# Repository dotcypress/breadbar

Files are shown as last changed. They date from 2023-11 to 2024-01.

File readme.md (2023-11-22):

# BreadBar

Minimal STM32G0 prototyping board.

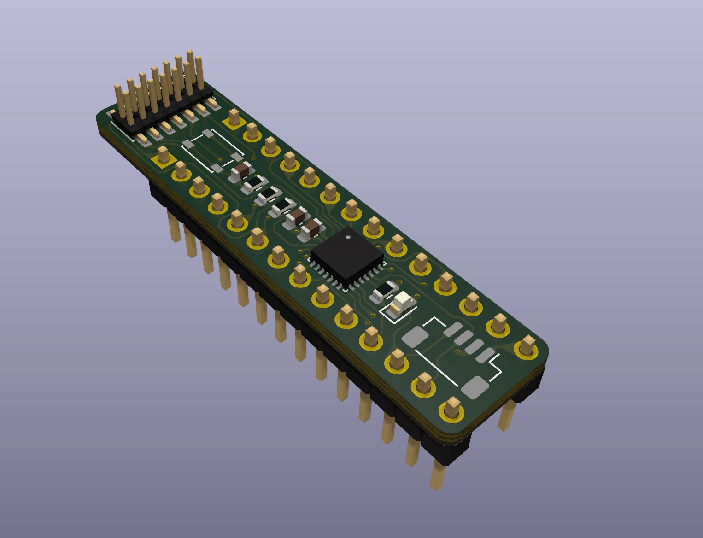
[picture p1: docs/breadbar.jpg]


## PCB

* [Schematics](docs/breadbar.pdf)
* [Gerber files](docs/breadbar_rev_0x01.zip)
* [Order PCB on OSHPark](https://oshpark.com/shared_projects/HnaNiZUA)

## Pinout

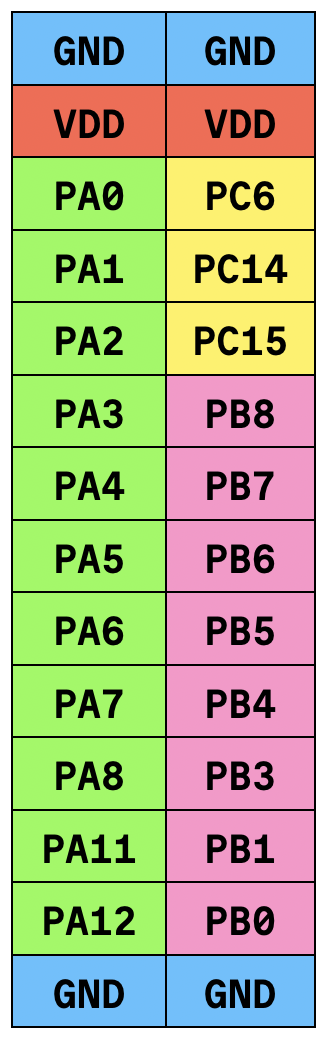
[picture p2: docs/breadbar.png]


## License

Licensed under either of

- Apache License, Version 2.0 ([LICENSE-APACHE](LICENSE-APACHE) or
  http://www.apache.org/licenses/LICENSE-2.0)
- MIT license ([LICENSE-MIT](LICENSE-MIT) or http://opensource.org/licenses/MIT)

at your option.

### Contribution

Unless you explicitly state otherwise, any contribution intentionally submitted
for inclusion in the work by you, as defined in the Apache-2.0 license, shall be
dual licensed as above, without any additional terms or conditions.

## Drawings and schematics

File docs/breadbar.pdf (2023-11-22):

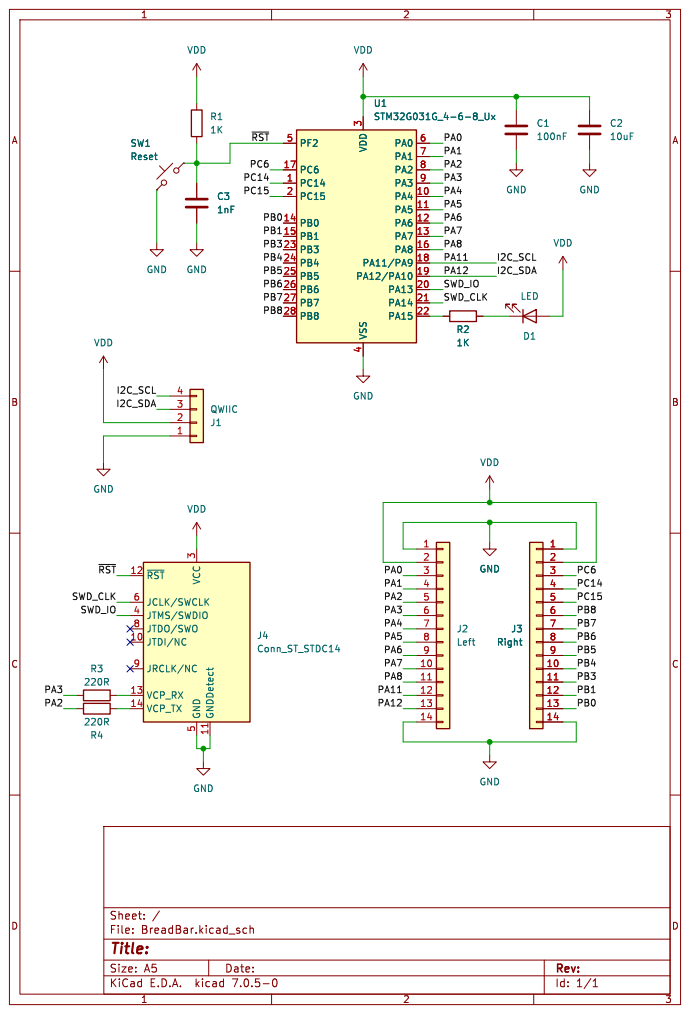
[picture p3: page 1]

VDD | VDD

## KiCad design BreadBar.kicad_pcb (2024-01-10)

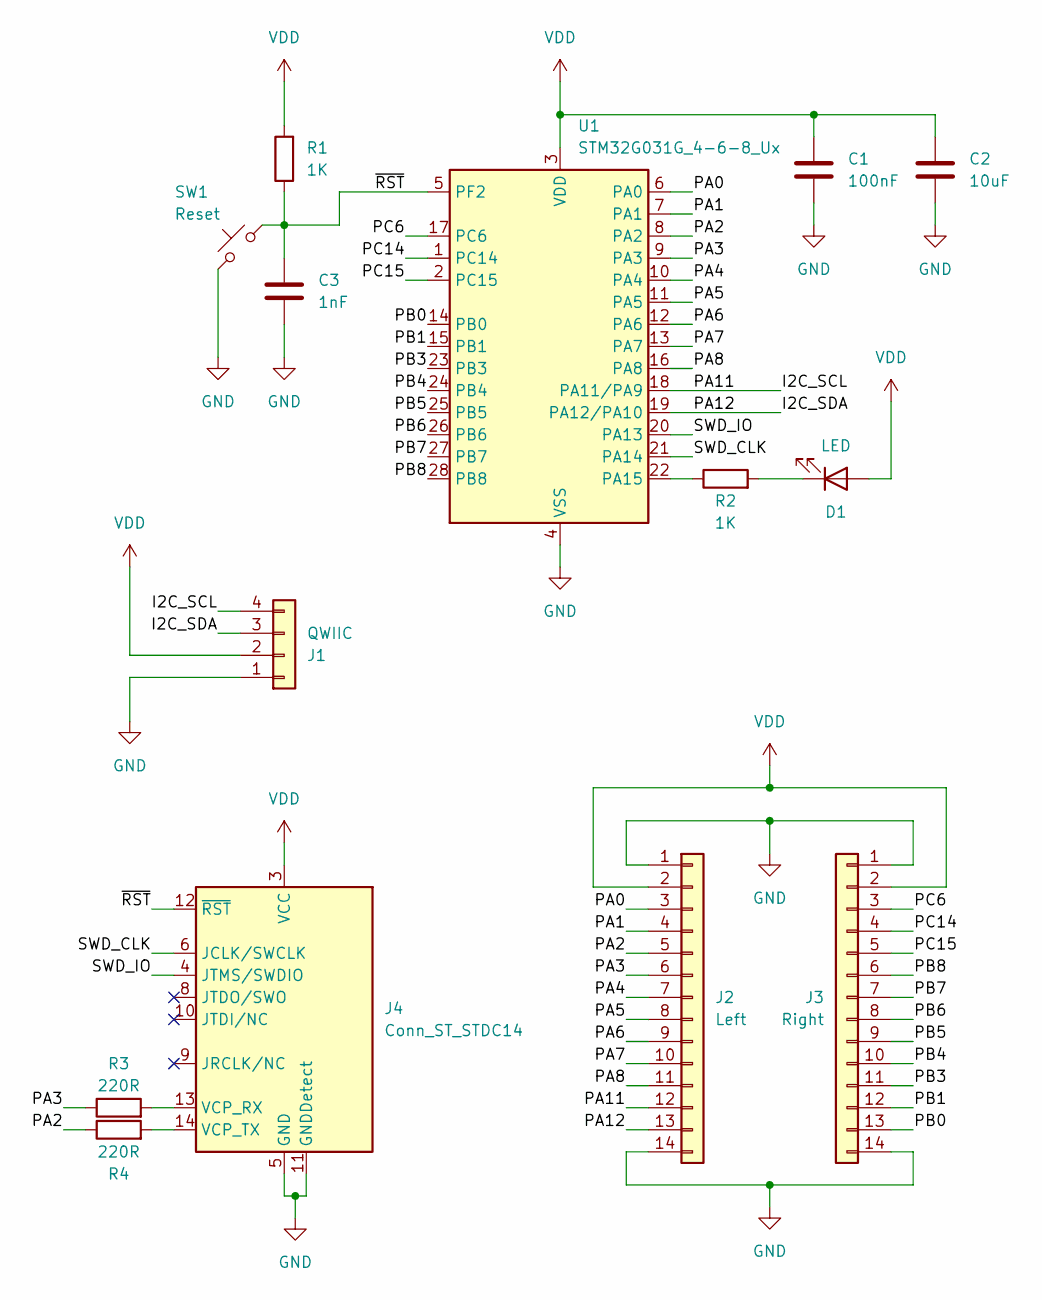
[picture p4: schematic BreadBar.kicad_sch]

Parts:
C1: 100nF; C_0603_1608Metric
C2: 10uF; C_0603_1608Metric
C3: 1nF; C_0603_1608Metric
D1: LED; LED_0603_1608Metric
J1: QWIIC; JST_SH_BM04B-SRSS-TB_1x04-1MP_P1.00mm_Vertical
J2: Left; PinHeader_1x14_P2.54mm_Vertical
J3: Right; PinHeader_1x14_P2.54mm_Vertical
J4: Conn_ST_STDC14; PinHeader_2x07_P1.27mm_Vertical_SMD
R1, R2: 1K; R_0603_1608Metric
R3, R4: 220R; R_0603_1608Metric
SW1: Reset; SW_SPST_PTS810
U1: STM32G031G_4-6-8_Ux; QFN-28_4x4mm_P0.5mm

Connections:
/I2C_SCL: J1.4, J2.12, U1.18 (PA11/PA9)
/I2C_SDA: J1.3, J2.13, U1.19 (PA12/PA10)
/PA0: J2.3, U1.6 (PA0)
/PA1: J2.4, U1.7 (PA1)
/PA2: J2.5, R4.1, U1.8 (PA2)
/PA3: J2.6, R3.1, U1.9 (PA3)
/PA4: J2.7, U1.10 (PA4)
/PA5: J2.8, U1.11 (PA5)
/PA6: J2.9, U1.12 (PA6)
/PA7: J2.10, U1.13 (PA7)
/PA8: J2.11, U1.16 (PA8)
/PB0: J3.13, U1.14 (PB0)
/PB1: J3.12, U1.15 (PB1)
/PB3: J3.11, U1.23 (PB3)
/PB4: J3.10, U1.24 (PB4)
/PB5: J3.9, U1.25 (PB5)
/PB6: J3.8, U1.26 (PB6)
/PB7: J3.7, U1.27 (PB7)
/PB8: J3.6, U1.28 (PB8)
/PC6: J3.3, U1.17 (PC6)
/PC14: J3.4, U1.1 (PC14)
/PC15: J3.5, U1.2 (PC15)
/SWD_CLK: J4.6 (JCLK/SWCLK), U1.21 (PA14)
/SWD_IO: J4.4 (JTMS/SWDIO), U1.20 (PA13)
/~RST: C3.1, J4.12 (~RST), R1.1, SW1.2, U1.5 (PF2)
GND: C1.2, C2.2, C3.2, J1.1, J2.1, J2.14, J3.1, J3.14, J4.5 (GND), J4.7 (GND), J4.11 (GNDDetect), SW1.1, U1.4 (VSS)
unnamed: D1.1 (K), R2.2
unnamed: J4.13 (VCP_RX), R3.2
unnamed: J4.14 (VCP_TX), R4.2
unnamed: R2.1, U1.22 (PA15)
VDD: C1.1, C2.1, D1.2 (A), J1.2, J2.2, J3.2, J4.3 (VCC), R1.2, U1.3 (VDD)

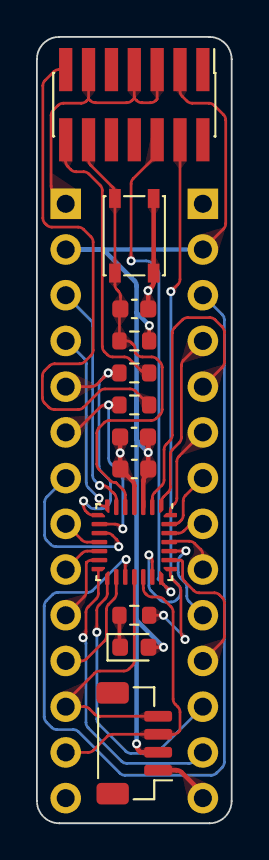
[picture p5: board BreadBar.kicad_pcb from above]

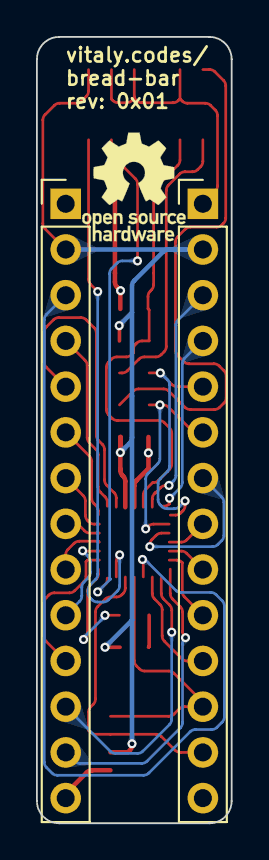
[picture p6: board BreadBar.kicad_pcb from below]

Board: 4 copper layers, 10.8 x 43.7 mm, 14 parts (2 on the bottom side), 31 nets.

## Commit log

2023-11-22 rev 0x01
    [BreadBar.kicad_pcb, BreadBar.kicad_sch]
2024-01-10 add BOM
    [BreadBar.kicad_pcb]
